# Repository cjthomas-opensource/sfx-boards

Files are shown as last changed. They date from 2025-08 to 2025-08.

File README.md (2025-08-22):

# Chris's Special-Effects Boards

## Overview

These are a series of hobby-project boards intended to produce sounds and
blinking lights. The boards are Arduino-compatible and small enough to be
packaged inside homemade toys.

Except where indicated otherwise, the files in this project are copyright (c)
2025 by Christopher Thomas and are released under the Creative Commons
Attribution-ShareAlike 4.0 International License.

**FIXME** - This really needs a user manual.

**FIXME** - Firmware code not yet folded into the repository.

## KiCad Configuration

In `Preferences`->`Configure Paths`, set `KICAD_EXT_VENDOR` to point to the
`vendor-kicad` folder.

## Folders

* `pcb-202009-9v` -- Compact board that sits on top of a 9v battery.
Needs an external clock to be programmed. Made with the "`pcb`" program
(now part of `gEDA`) rather than with KiCad.
* `pcb-202502` -- Feature-rich board with terminal block connections. Bulky
and very expensive. Made with KiCad.
* `vendor-datasheets` -- Datasheets. Under vendor copyright.
* `vendor-kicad` -- Vendor-supplied KiCad files, with additions and
modifications where appropriate. Under vendor copyright.
* `vendor-models` -- Vendor-supplied geometry models. Under vendor copyright.

## Gallery

### 2020 Board:
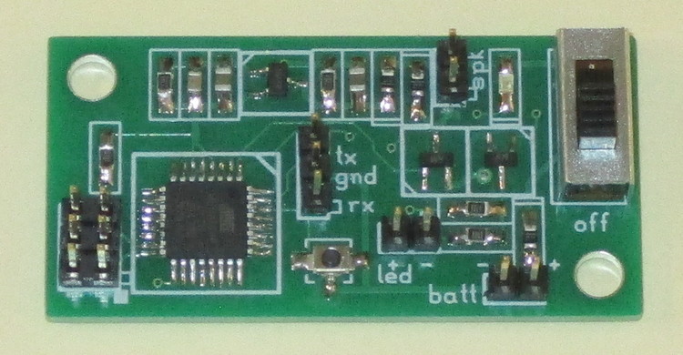
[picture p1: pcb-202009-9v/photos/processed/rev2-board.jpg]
2020 Board

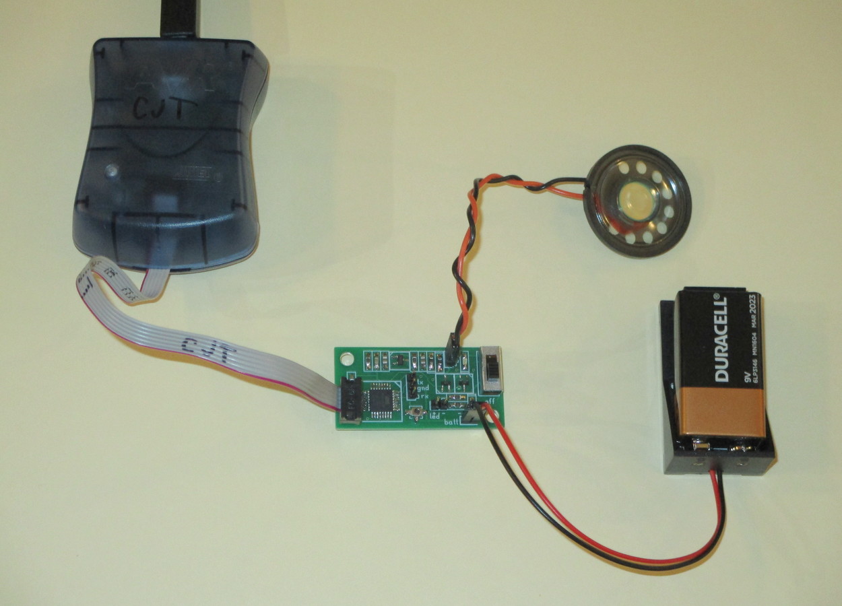
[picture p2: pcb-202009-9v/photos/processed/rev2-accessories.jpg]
2020 System


### 2025 Board:
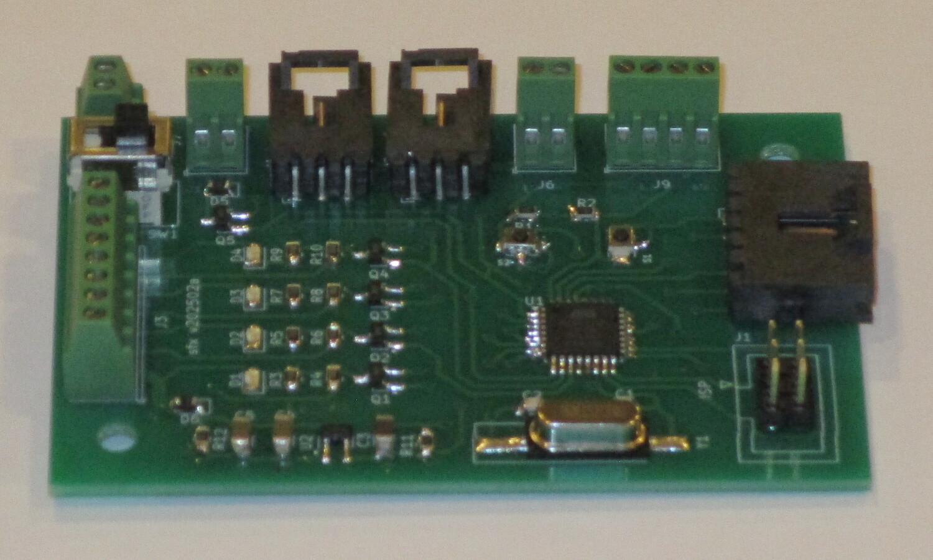
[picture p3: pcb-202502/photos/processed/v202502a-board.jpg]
2025 Board

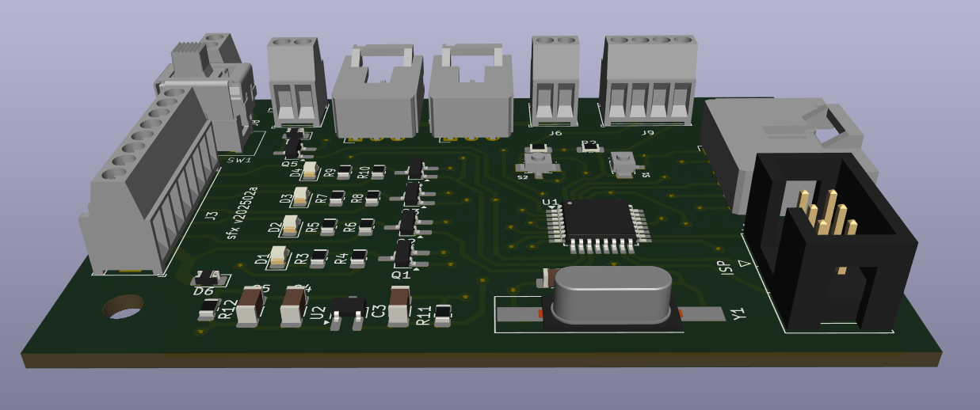
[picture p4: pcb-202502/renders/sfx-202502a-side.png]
2025 Render

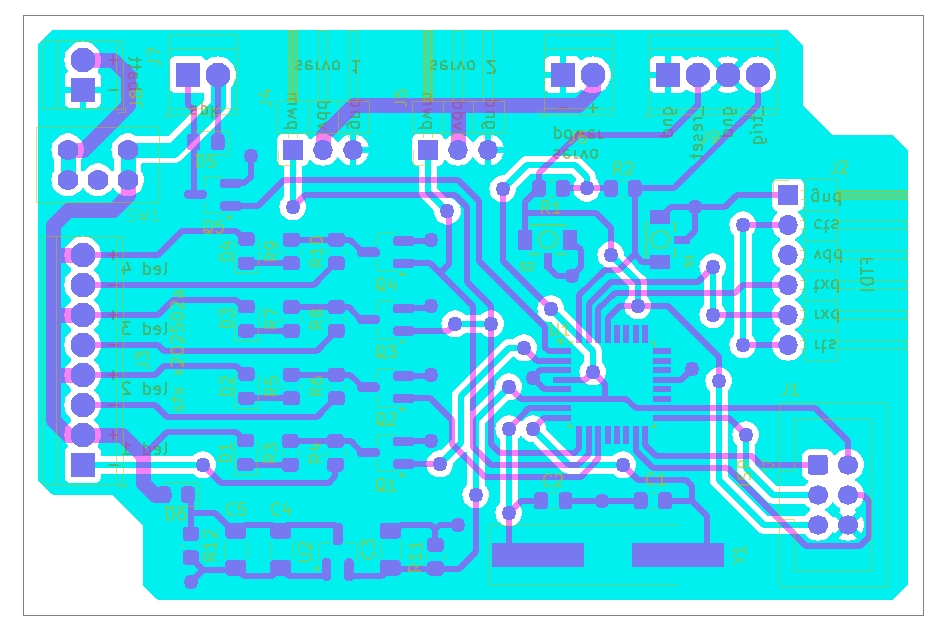
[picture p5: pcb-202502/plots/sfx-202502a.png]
2025 Layout

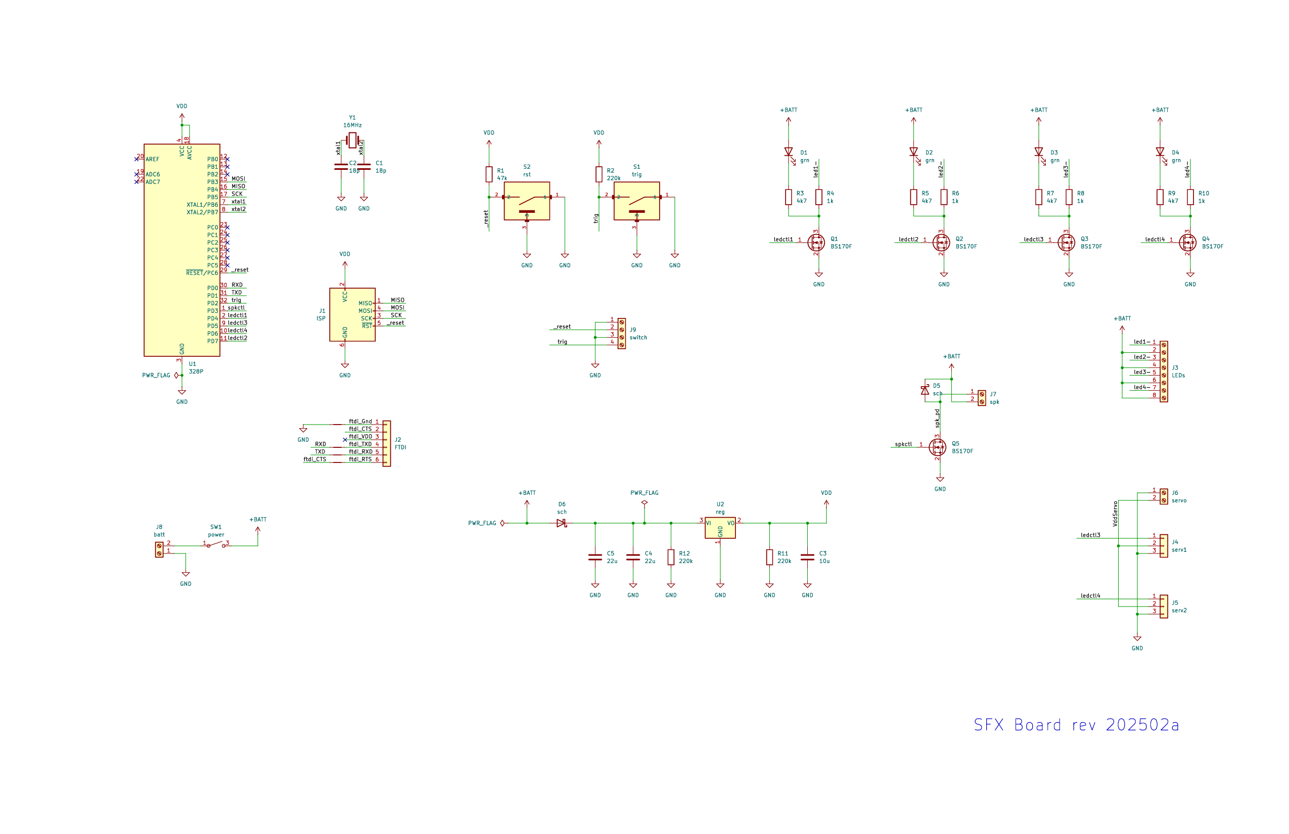
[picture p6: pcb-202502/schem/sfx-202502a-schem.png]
2025 Schematic


*This is the end of the file.*

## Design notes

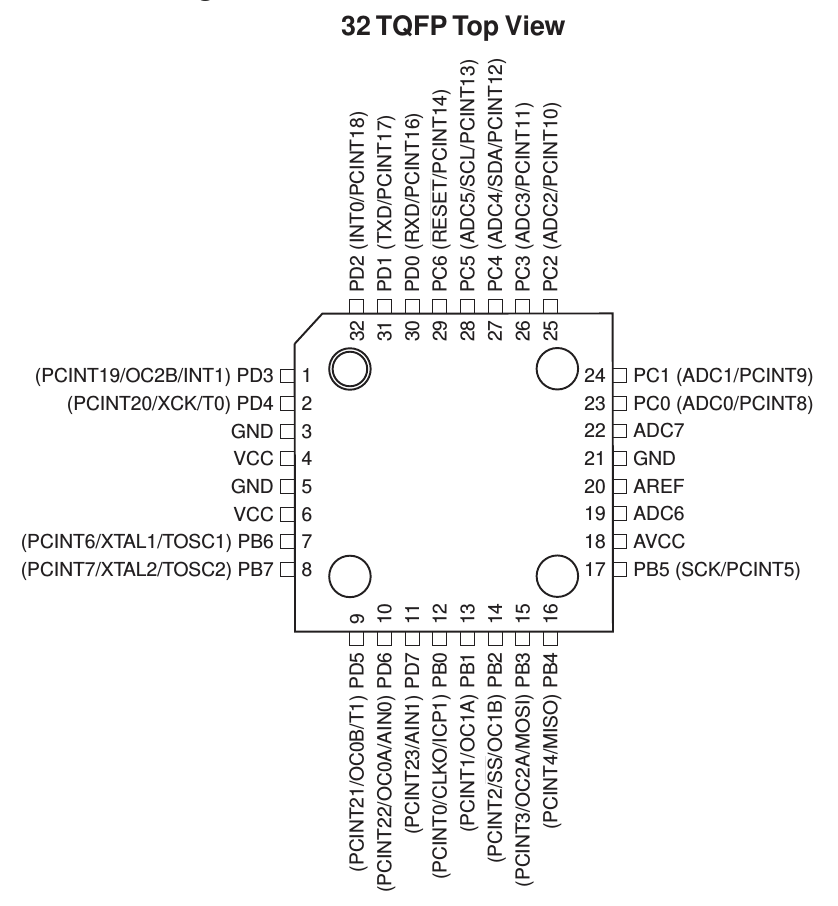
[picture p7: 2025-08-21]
vendor-datasheets/atmega328p-tqfp32-pinout.png

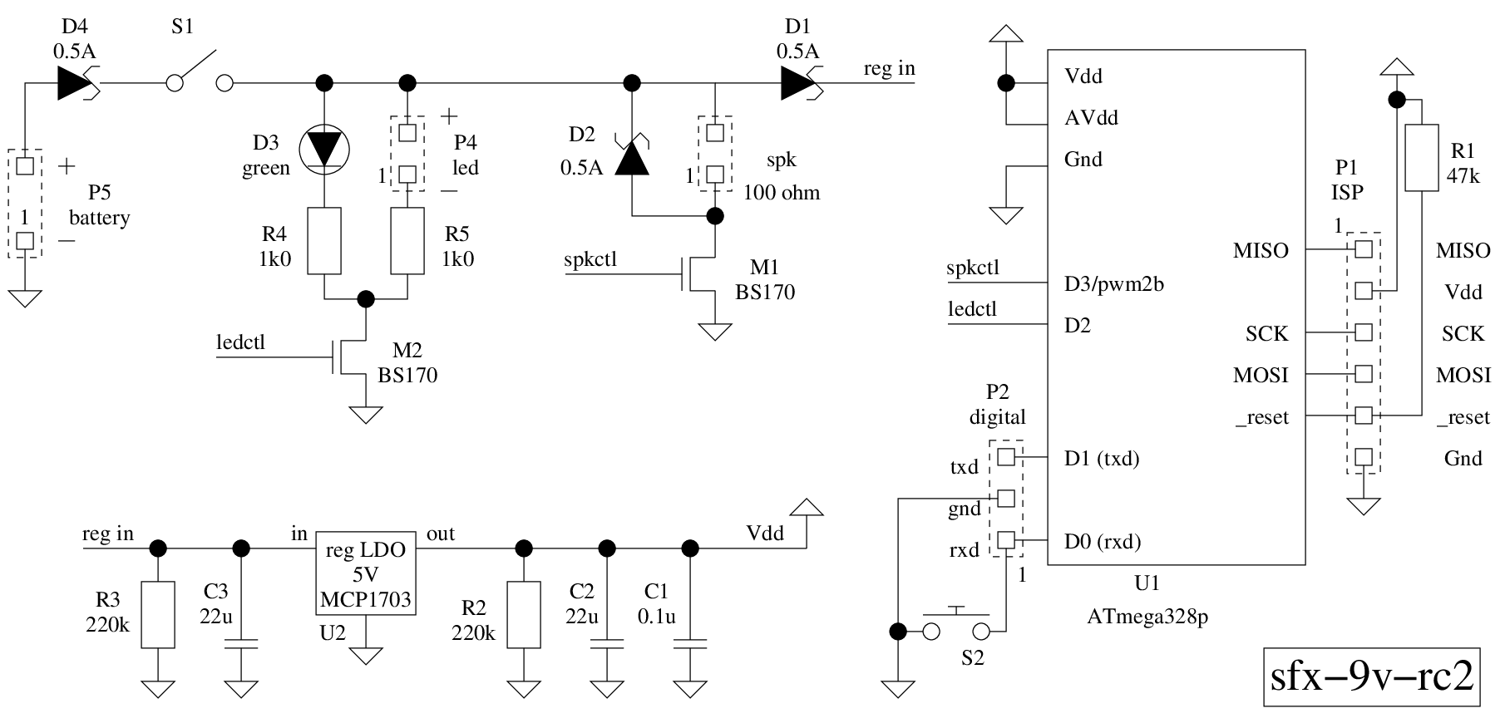
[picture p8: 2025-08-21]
pcb-202009-9v/schematic/sfx-9v-rc2-schem.png

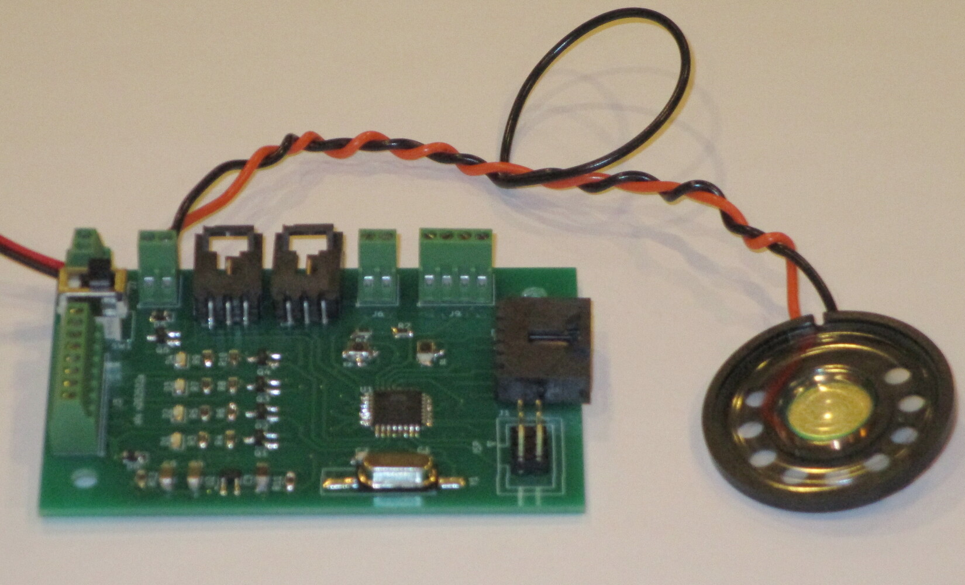
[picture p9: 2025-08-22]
pcb-202502/photos/processed/v202502a-speaker.jpg

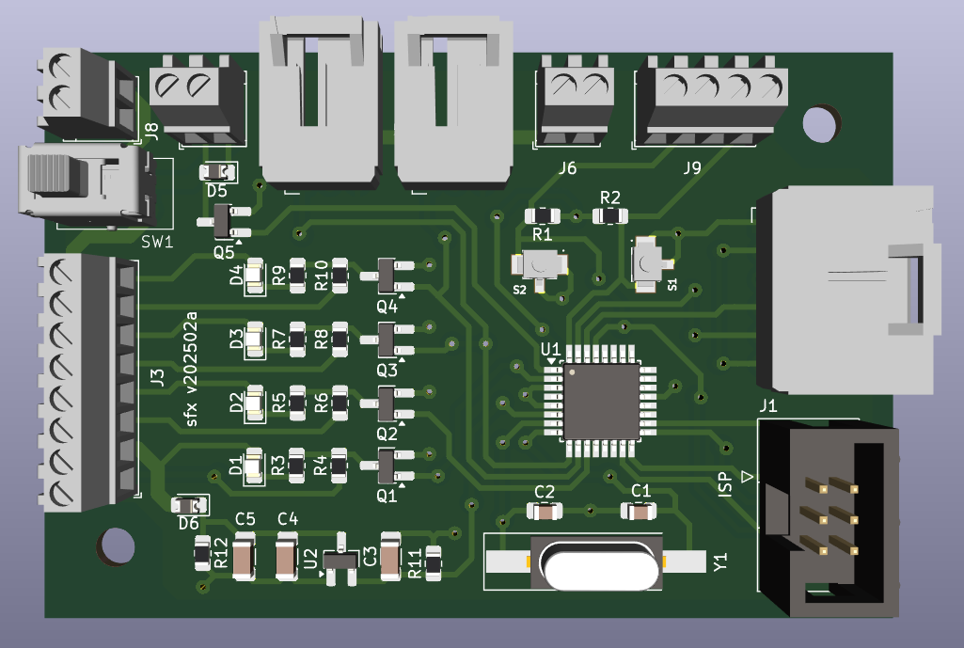
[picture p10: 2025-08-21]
pcb-202502/renders/sfx-202502a-top.png

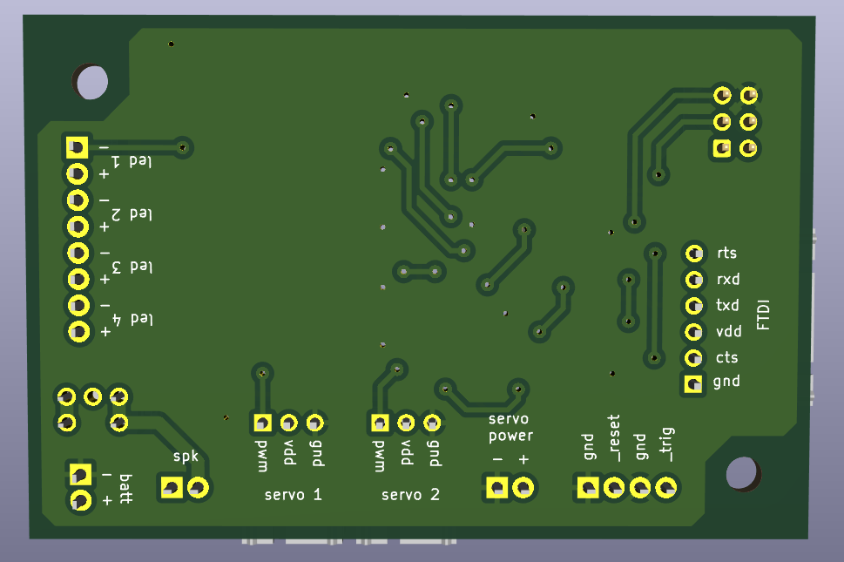
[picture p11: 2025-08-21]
pcb-202502/renders/sfx-202502a-bottom.png

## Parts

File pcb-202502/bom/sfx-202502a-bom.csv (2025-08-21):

Reference | Value | Qty | DNP | DkeyPart | MfgPart | Manufacturer
C1,C2 | 18p | 2 |  | 399-C0805C180K5GACTUCT-ND | C0805C180K5GACTU | Kemet
C3 | 10u | 1 |  | 311-1959-1-ND | CC1206KKX7R8BB106 | Yageo
C4,C5 | 22u | 2 |  | 13-CC1206KFX5R8BB226CT-ND | CC1206KFX5R8BB226 | Yageo
D1,D2,D3,D4 | grn | 4 |  | 754-1438-1-ND | APT2012ZGC | Kingbright
D5,D6 | sch | 2 |  | 478-7802-1-ND | SD0805S040S0R5 | Kyocera AVX
J1 | ISP | 1 |  | A122759-ND | 1761681-1 | TE Connectivity
J2 | FTDI | 1 |  | A28630-ND | 103906-5 | TE Connectivity
J3 | LEDs | 1 |  | A98338-ND | 282834-8 | TE Connectivity
J4 | serv1 | 1 |  | A28621-ND | 103906-2 | TE Connectivity
J5 | serv2 | 1 |  | A28621-ND | 103906-2 | TE Connectivity
J6 | servo | 1 |  | A98333-ND | 282834-2 | TE Connectivity
J7 | spk | 1 |  | A98333-ND | 282834-2 | TE Connectivity
J8 | batt | 1 |  | A98333-ND | 282834-2 | TE Connectivity
J9 | switch | 1 |  | A98335-ND | 282834-4 | TE Connectivity
Q1,Q2,Q3,Q4,Q5 | BS170F | 5 |  | BS170FCT-ND | BS170FTA | Diodes Incorporated
R1 | 47k | 1 |  | 311-47.0KCRCT-ND | RC0805FR-0747KL | Yageo
R2,R11,R12 | 220k | 3 |  | 311-220KCRCT-ND | RC0805FR-07220KL | Yageo
R3,R5,R7,R9 | 4k7 | 4 |  | 311-4.70KCRCT-ND | RC0805FR-074K7L | Yageo
R4,R6,R8,R10 | 1k | 4 |  | 311-1.00KCRCT-ND | RC0805FR-071KL | Yageo
S1 | trig | 1 |  | SW1021CT-ND | B3U-1100P | Omron Electronics
S2 | rst | 1 |  | SW1021CT-ND | B3U-1100P | Omron Electronics
SW1 | power | 1 |  | CKN1812-ND | ES02MCBE | CK Components
U1 | 328P | 1 |  | ATMEGA328P-ANRCT-ND | ATMEGA328P-ANR | Atmel
U2 | reg | 1 |  | MCP1703AT-5002E/CBCT-ND | MCP1703AT-5002E/CB | Microchip Technology
Y1 | 16MHz | 1 |  | 50-ECS-160-18-5PX-CKM-CT-ND | ECS-160-18-5PX-CKM-TR | ECS Inc

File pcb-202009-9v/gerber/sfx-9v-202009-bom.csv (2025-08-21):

Designator | Manufacturer Part Number | Qty | Link
C1 | CC0805MRX7R8BB104 | 1 | https://www.digikey.com/product-detail/en/yageo/CC0805MRX7R8BB104/311-4348-1-ND
C2, C3 | CC0805MKX5R8BB226 | 2 | https://www.digikey.com/product-detail/en/yageo/CC0805MKX5R8BB226/311-1903-1-ND
D1, D2, D4 | SD0805S040S0R5 | 2 | https://www.digikey.com/product-detail/en/avx-corporation/SD0805S040S0R5/478-7802-1-ND
D3 | APT2012ZGC | 1 | https://www.digikey.com/product-detail/en/kingbright/APT2012ZGC/754-1438-1-ND
M1, M2 | BS170FTA | 2 | https://www.digikey.com/product-detail/en/diodes-incorporated/BS170FTA/BS170FCT-ND
P1 | TSW-103-07-G-D | 1 | https://www.digikey.com/product-detail/en/samtec-inc/TSW-103-07-G-D/SAM1028-03-ND
P2 | TSW-103-07-G-S | 1 | https://www.digikey.com/product-detail/en/samtec-inc/TSW-103-07-G-S/SAM1029-03-ND
P3, P4, P5 | TSW-102-07-G-S | 3 | https://www.digikey.com/product-detail/en/samtec-inc/TSW-102-07-G-S/SAM1029-02-ND
R1 | KTR10EZPF4702 | 1 | https://www.digikey.com/product-detail/en/rohm-semiconductor/KTR10EZPF4702/RHM47-0KAHCT-ND
R2 R3 | KTR10EZPF2203 | 2 | https://www.digikey.com/product-detail/en/rohm-semiconductor/KTR10EZPF2203/RHM220KAHCT-ND
R4 R5 | ESR10EZPF1001 | 2 | https://www.digikey.com/product-detail/en/rohm-semiconductor/ESR10EZPF1001/RHM1-00KAECT-ND
S1 | SLB12814 | 1 | https://www.digikey.com/product-detail/en/apem-inc/SLB12814/679-3547-ND
S2 | B3U-1100P | 1 | https://www.digikey.com/product-detail/en/omron-electronics-inc-emc-div/B3U-1100P/SW1021CT-ND
U1 | ATMEGA328P-AU | 1 | https://www.digikey.com/product-detail/en/microchip-technology/ATMEGA328P-AU/ATMEGA328P-AU-ND
U2 | MCP1703T-5002E-CB | 1 | https://www.digikey.com/product-detail/en/microchip-technology/MCP1703T-5002E-CB/MCP1703T-5002E-CBCT-ND

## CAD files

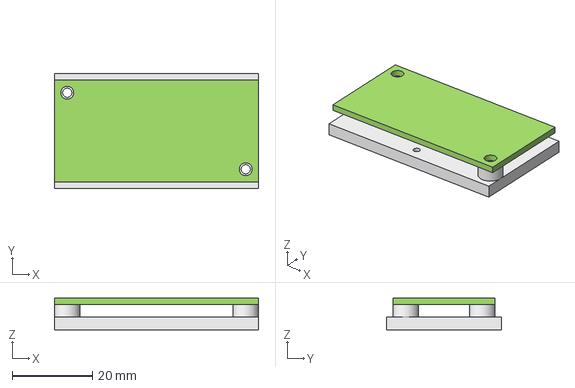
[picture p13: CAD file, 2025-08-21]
pcb-202009-9v/mech/adapter-sfx-9v.fcstd
50.8 x 28.6 x 7.94 mm
adapter with holes
pcb

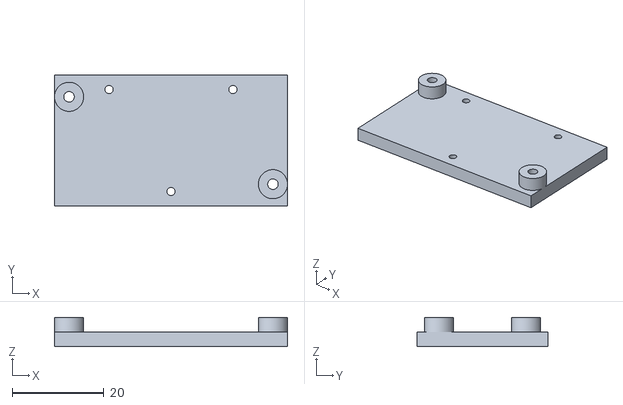
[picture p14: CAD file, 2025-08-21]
pcb-202009-9v/mech/meshes/adapter-sfx-9v.stl
50.8 x 28.6 x 6.35

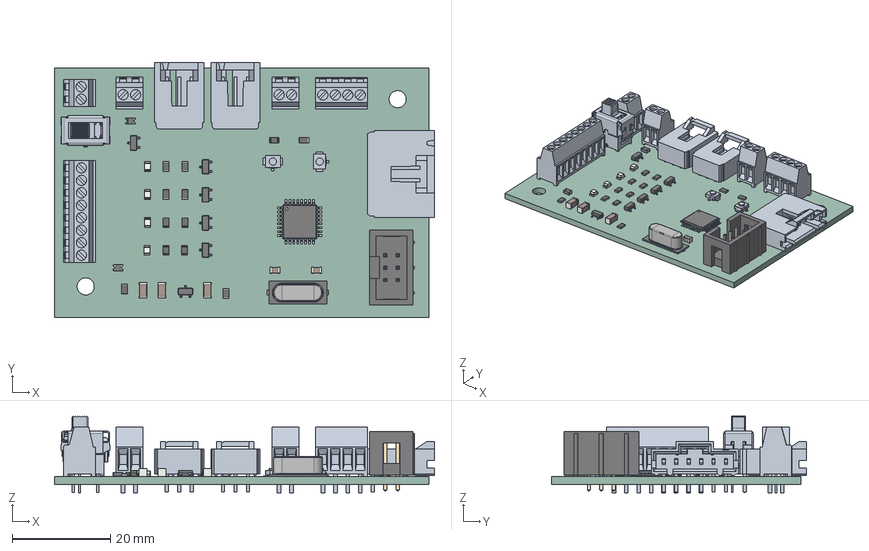
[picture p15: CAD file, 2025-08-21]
pcb-202502/model/sfx-202502a.step
77.3 x 51.9 x 15.7 mm
R_0805_2012Metric x 12
C_0805_2012Metric x 2
LED_0805_2012Metric x 4
SOT_23 x 6
C_1206_3216Metric x 3
TQFP_32_7x7mm_P08mm
B3U_1100P[] x 2
C-282834-8
D_0805 x 2
Crystal_SMD_HC49-SD
ES02MCBE
IDC_Header_2x03_P254mm_Vertical
C-282834-4
sfx-202502_PCB

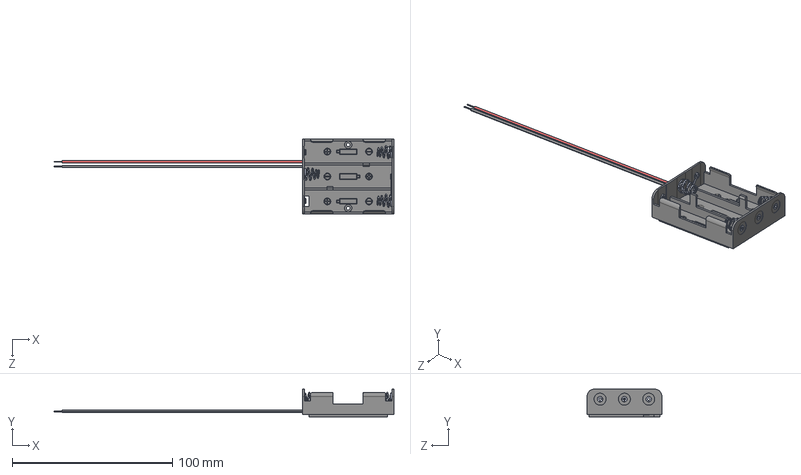
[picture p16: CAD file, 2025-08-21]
vendor-kicad/mpd-batt-models/BH3AA-W.step
212.1 x 17.4 x 46.6 mm

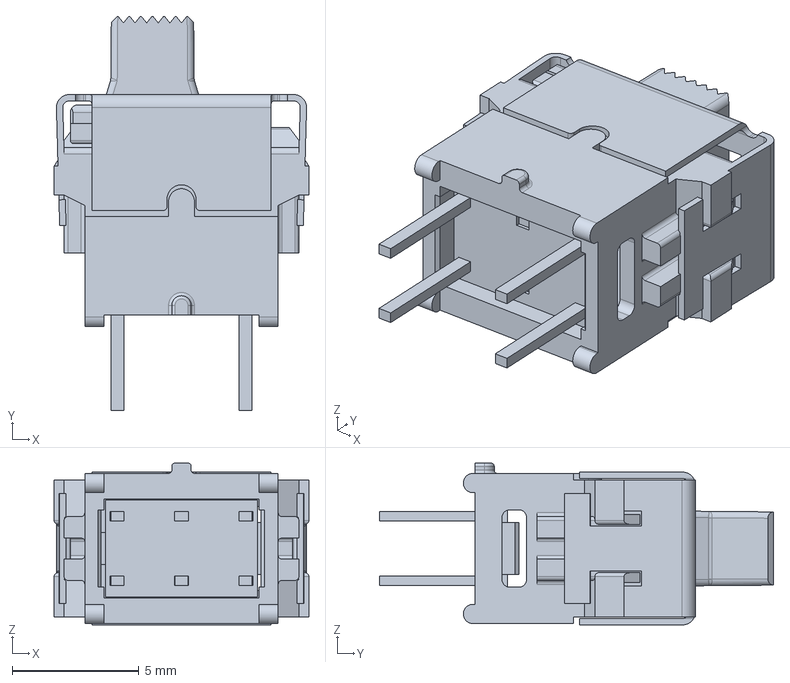
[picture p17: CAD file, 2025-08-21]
vendor-kicad/switch-ck-spst-vert-ES02MCBE/ES02MCBE.step
10.0 x 15.5 x 6.38 mm
ES02MCBE_PART1
ES02MCBE_PART2
ES02MCBE_PART3

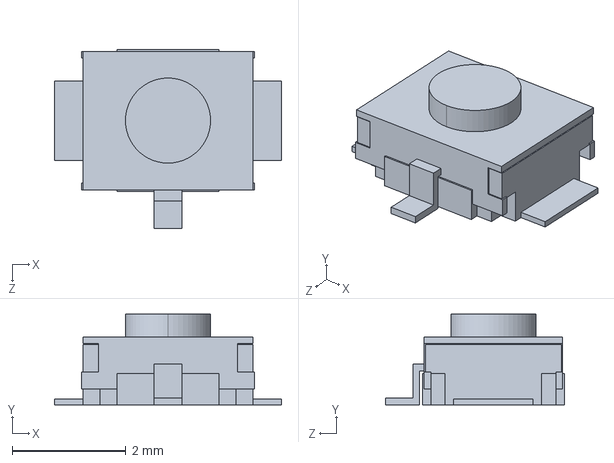
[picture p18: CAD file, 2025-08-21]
vendor-kicad/switch-smt-pb-Omron-B3U_1100P/B3U-1100P.step
4.00 x 1.60 x 3.15 mm

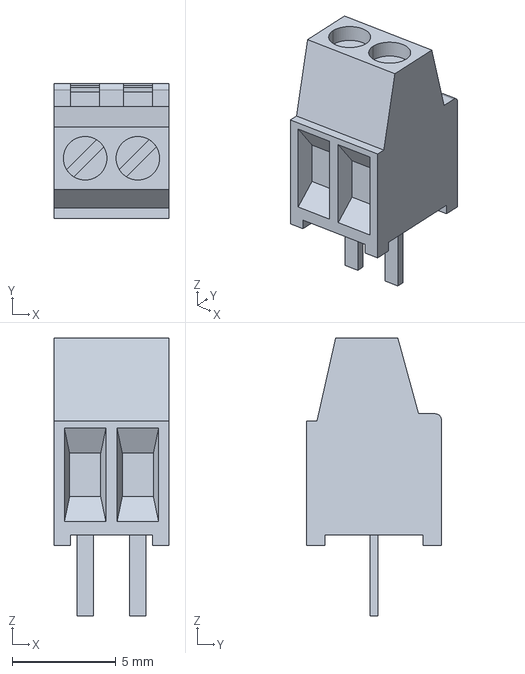
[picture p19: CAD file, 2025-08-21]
vendor-kicad/te-conn-models/term-2pos-100mil-282834-2.stp
5.54 x 6.50 x 13.4 mm

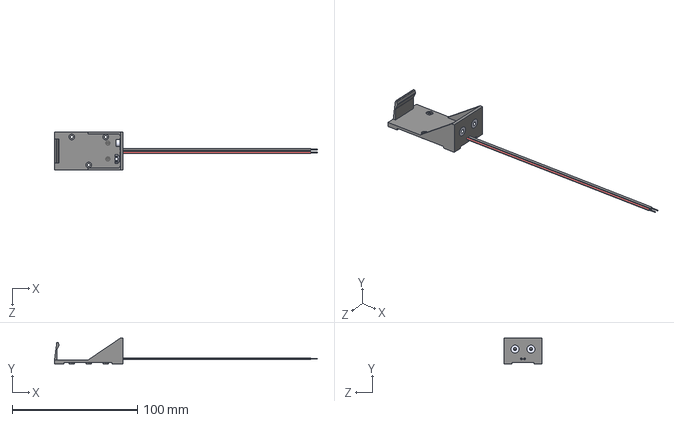
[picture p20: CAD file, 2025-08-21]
vendor-models/BH9VW.step
209.6 x 20.6 x 30.0 mm

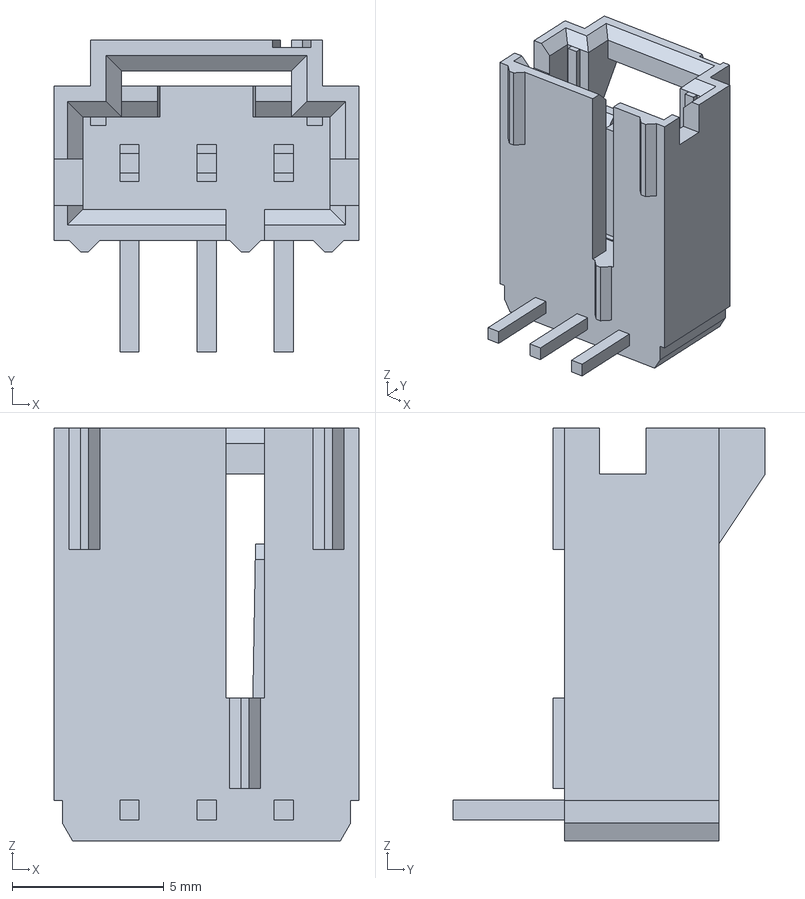
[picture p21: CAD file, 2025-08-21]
vendor-kicad/te-conn-models/conn-01x03-m-shr-103906-2.stp
10.0 x 10.3 x 13.6 mm

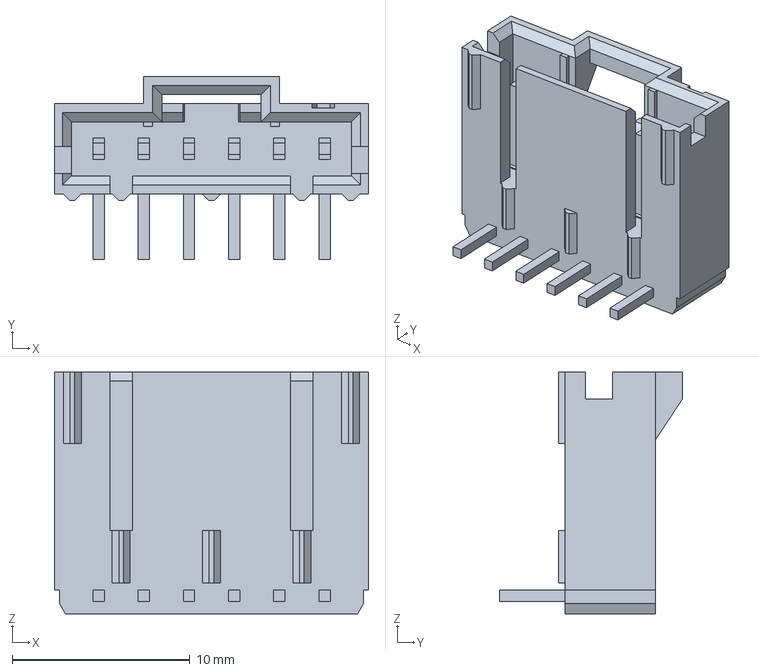
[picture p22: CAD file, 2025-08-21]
vendor-kicad/te-conn-models/conn-01x06-m-shr-103906-5.stp
17.7 x 10.3 x 13.6 mm

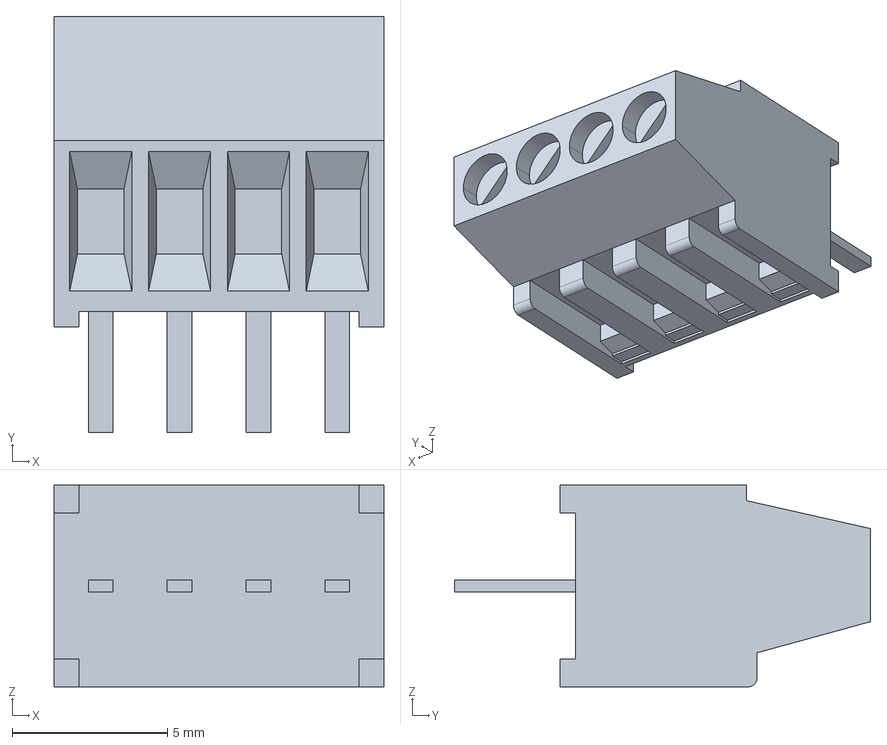
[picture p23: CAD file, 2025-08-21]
vendor-kicad/te-conn-models/term-4pos-100mil-282834-4.stp
10.6 x 13.4 x 6.50 mm

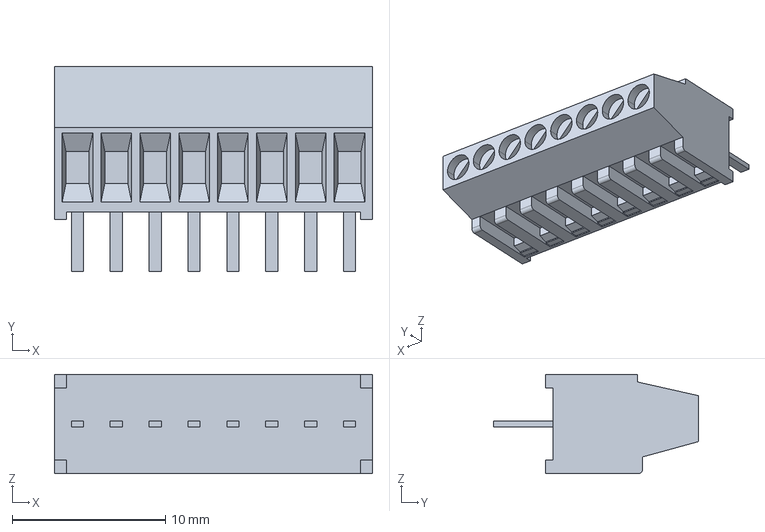
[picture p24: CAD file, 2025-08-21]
vendor-kicad/te-conn-models/term-8pos-100mil-282834-8.stp
20.8 x 13.4 x 6.50 mm

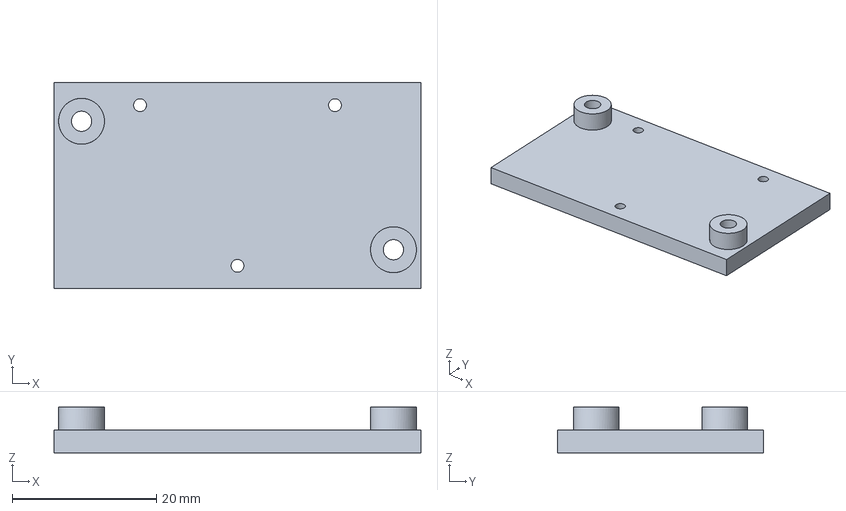
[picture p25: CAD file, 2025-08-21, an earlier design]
pcb-202009-9v/mech/iges/adapter-sfx-9v-rc2-deprecated.iges
50.8 x 28.6 x 6.35 mm

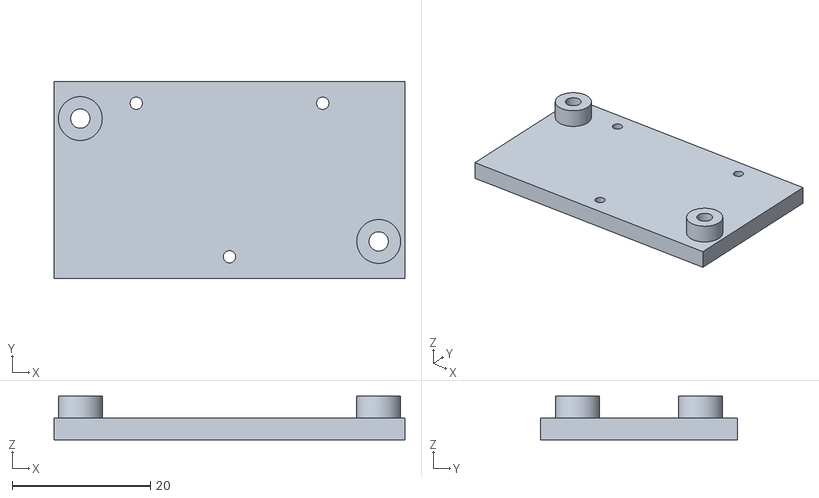
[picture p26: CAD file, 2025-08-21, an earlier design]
pcb-202009-9v/mech/meshes/adapter-sfx-9v-rc2-deprecated.stl
50.8 x 28.6 x 6.35

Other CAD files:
pcb-202009-9v/mech/iges/adapter-sfx-9v.iges

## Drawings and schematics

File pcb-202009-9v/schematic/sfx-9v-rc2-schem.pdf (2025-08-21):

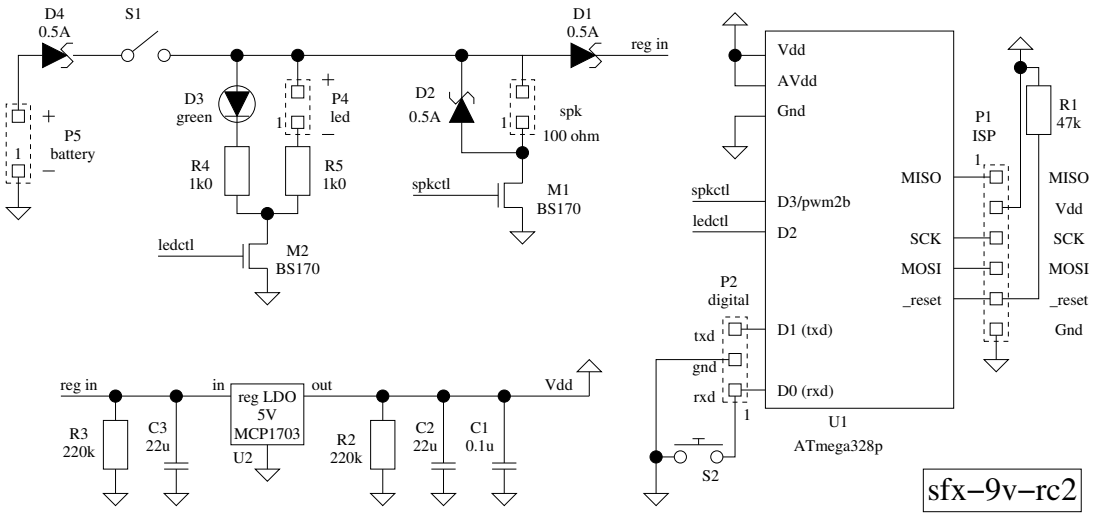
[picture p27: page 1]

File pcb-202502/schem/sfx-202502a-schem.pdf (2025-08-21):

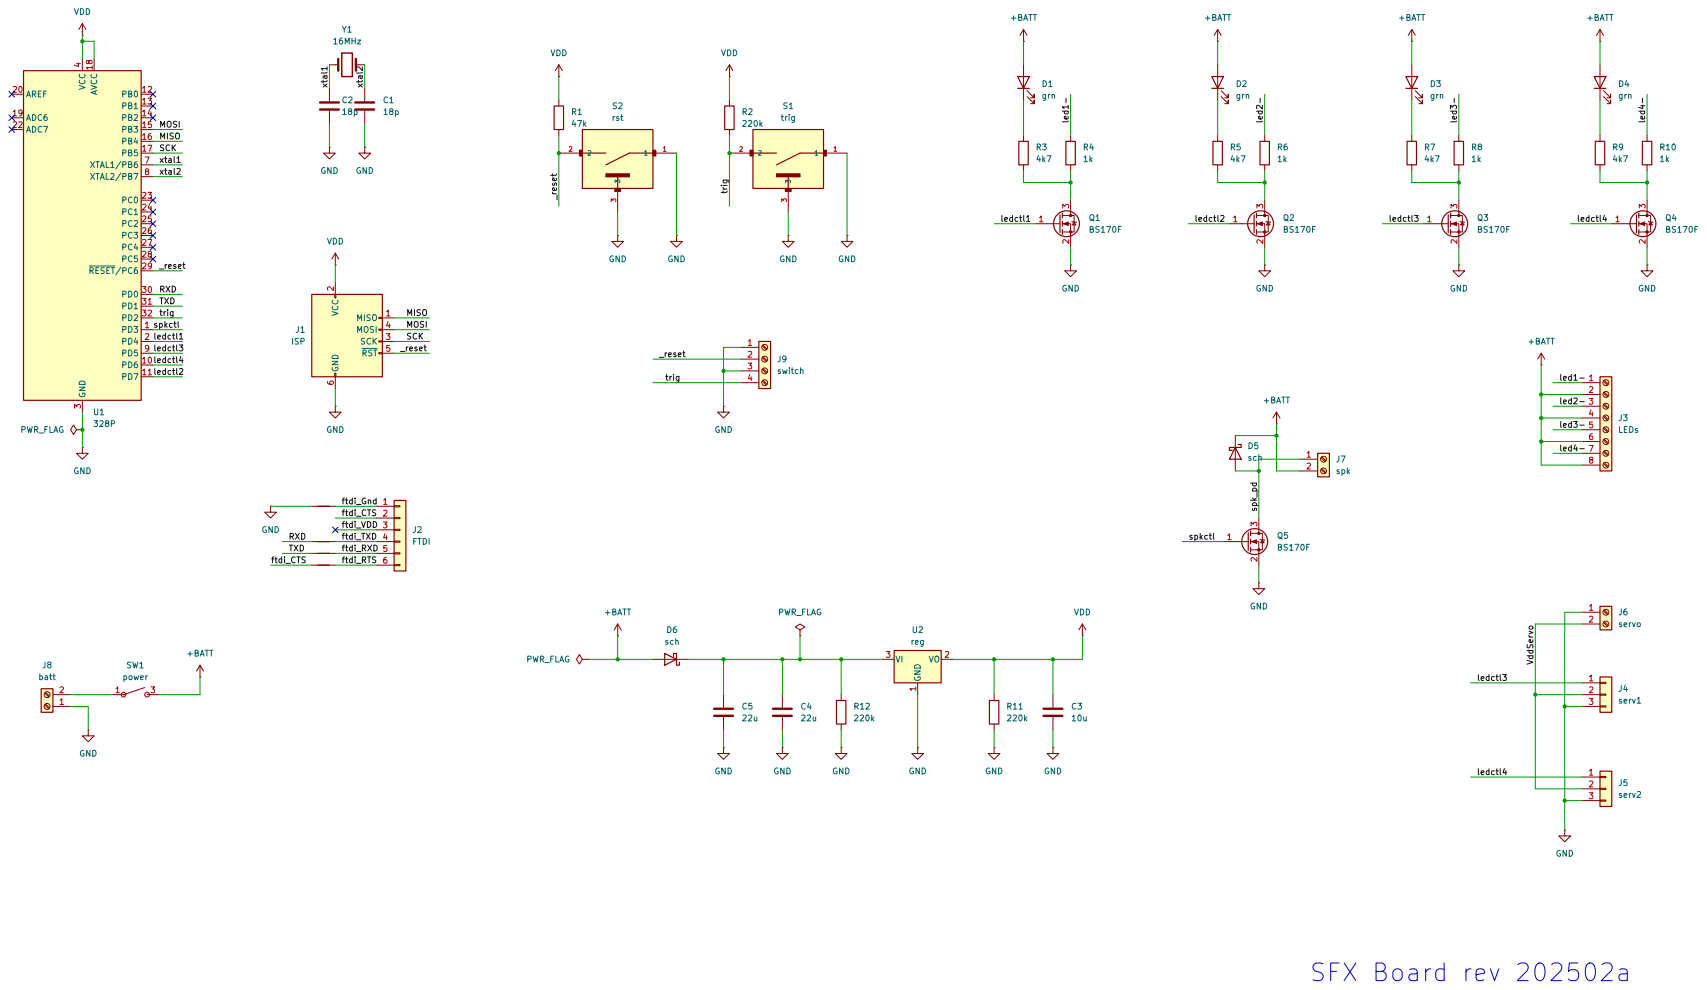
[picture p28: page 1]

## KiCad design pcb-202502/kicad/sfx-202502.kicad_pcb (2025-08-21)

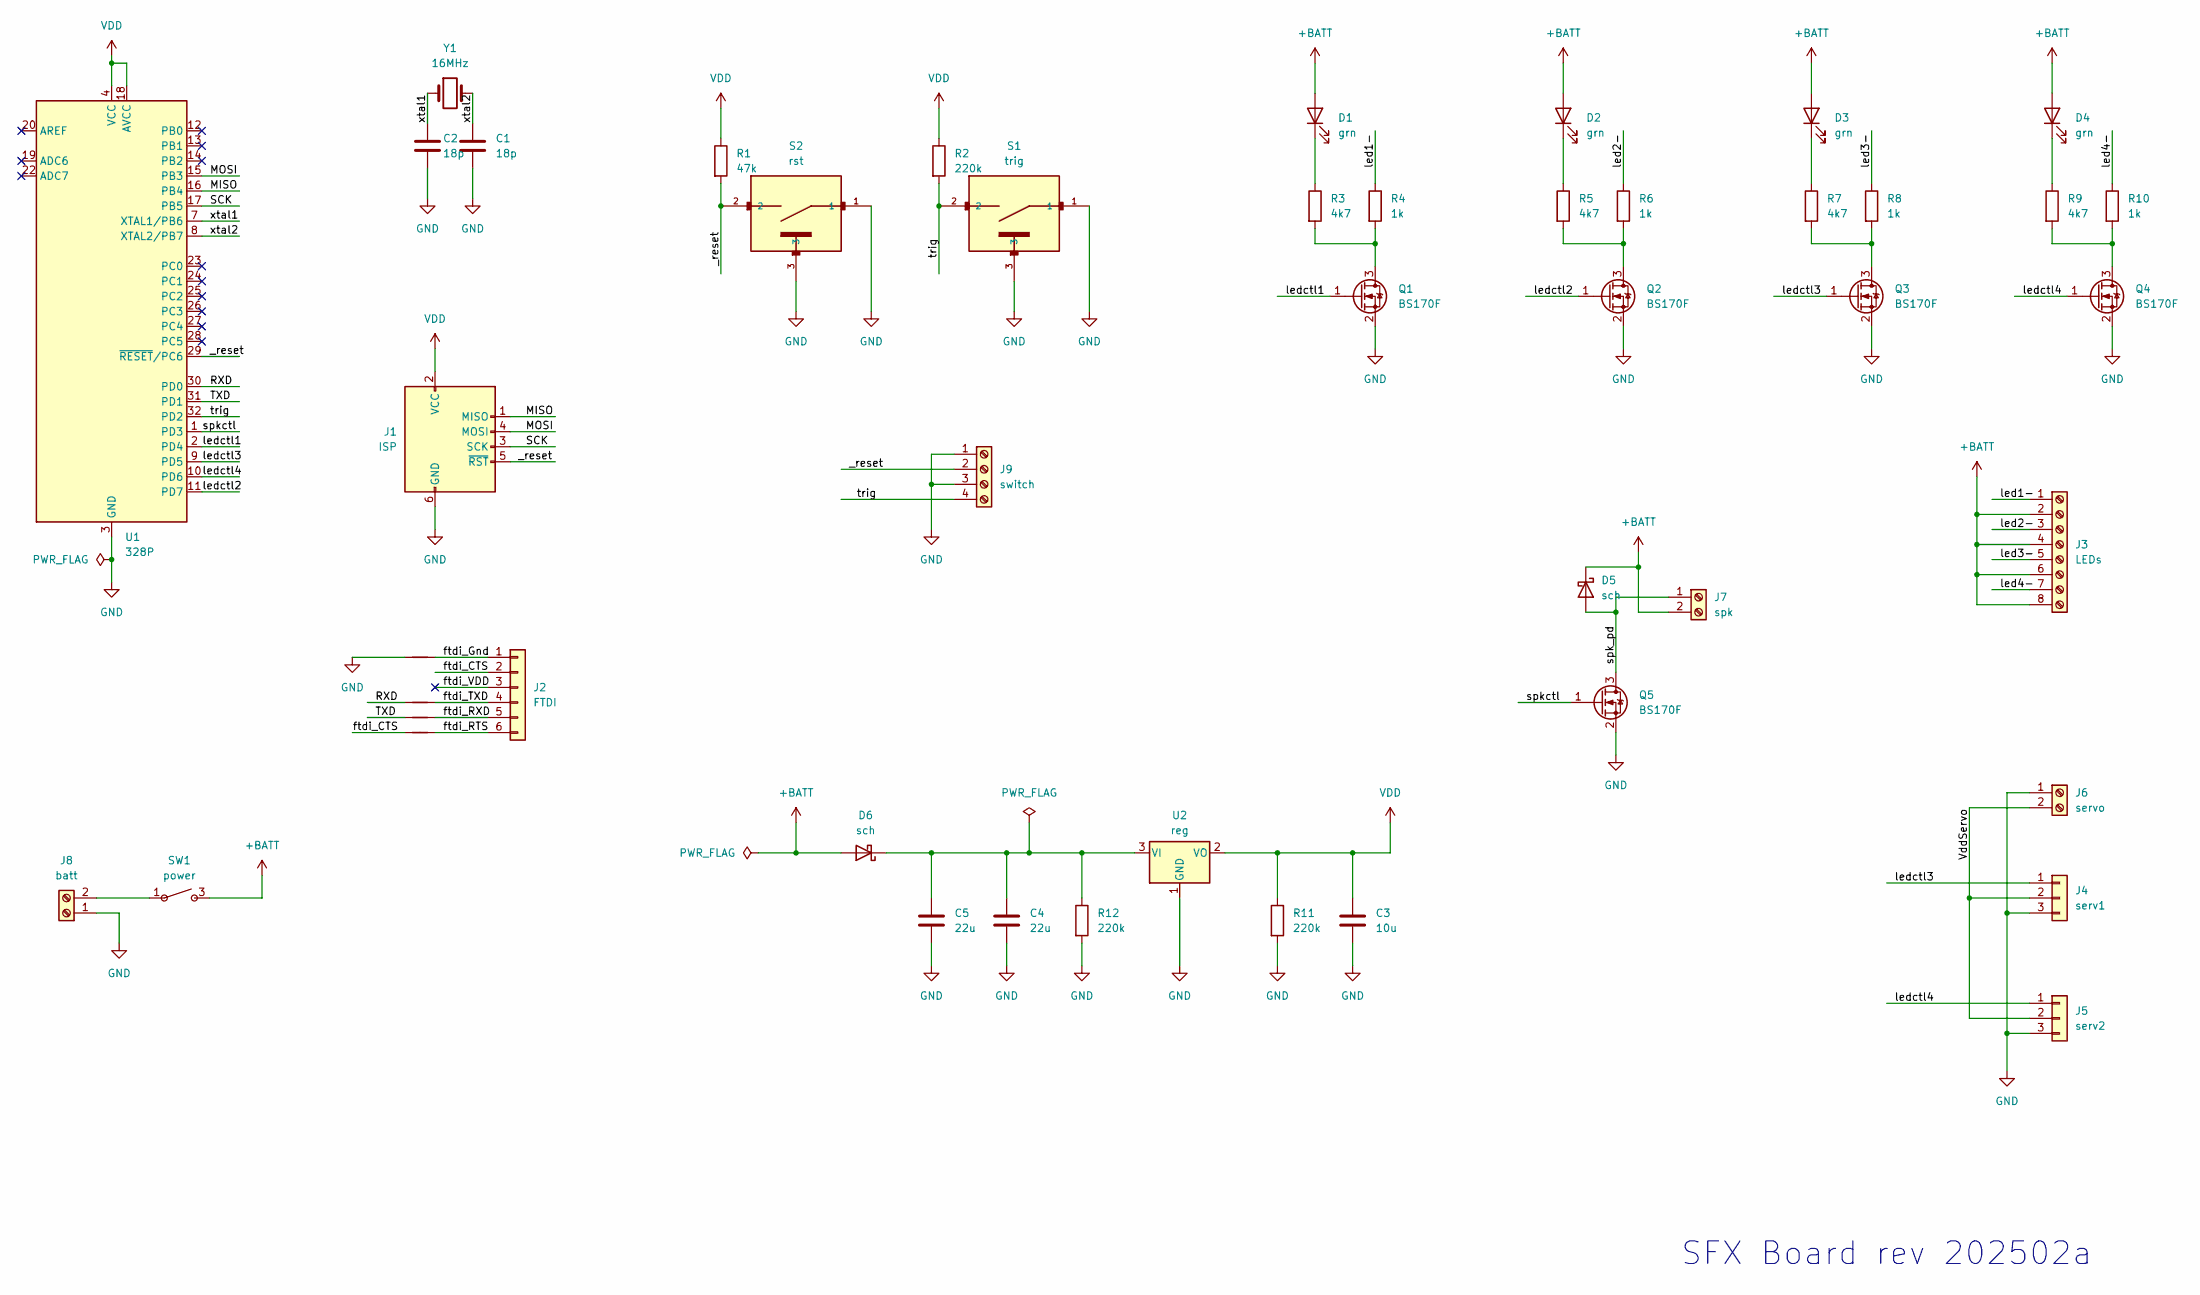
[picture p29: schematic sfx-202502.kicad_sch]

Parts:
C1, C2: 18p; C_0805_2012Metric_Pad1.18x1.45mm_HandSolder; MfgPart C0805C180K5GACTU
C3: 10u; C_1206_3216Metric_Pad1.33x1.80mm_HandSolder; MfgPart CC1206KKX7R8BB106
C4, C5: 22u; C_1206_3216Metric_Pad1.33x1.80mm_HandSolder; MfgPart CC1206KFX5R8BB226
D1, D2, D3, D4: grn; LED_0805_2012Metric_Pad1.15x1.40mm_HandSolder; MfgPart APT2012ZGC
D5, D6: sch; D_0805_2012Metric_Pad1.15x1.40mm_HandSolder; MfgPart SD0805S040S0R5
J1: ISP; IDC-Header_2x03_P2.54mm_Vertical; MfgPart 1761681-1
J2: FTDI; PinHeader_1x06_P2.54mm_Horizontal; MfgPart 103906-5
J3: LEDs; TerminalBlock_TE_282834-8_1x08_P2.54mm_Horizontal; MfgPart 282834-8
J4: serv1; PinHeader_1x03_P2.54mm_Horizontal; MfgPart 103906-2
J5: serv2; PinHeader_1x03_P2.54mm_Horizontal; MfgPart 103906-2
J6: servo; TerminalBlock_TE_282834-2_1x02_P2.54mm_Horizontal; MfgPart 282834-2
J7: spk; TerminalBlock_TE_282834-2_1x02_P2.54mm_Horizontal; MfgPart 282834-2
J8: batt; TerminalBlock_TE_282834-2_1x02_P2.54mm_Horizontal; MfgPart 282834-2
J9: switch; TerminalBlock_TE_282834-4_1x04_P2.54mm_Horizontal; MfgPart 282834-4
NT1, NT2, NT3, NT4: NetTie_2; NetTie-2_SMD_Pad0.5mm
Q1, Q2, Q3, Q4, Q5: BS170F; SOT-23_Handsoldering; MfgPart BS170FTA
R1: 47k; R_0805_2012Metric_Pad1.20x1.40mm_HandSolder; MfgPart RC0805FR-0747KL
R2, R11, R12: 220k; R_0805_2012Metric_Pad1.20x1.40mm_HandSolder; MfgPart RC0805FR-07220KL
R3, R5, R7, R9: 4k7; R_0805_2012Metric_Pad1.20x1.40mm_HandSolder; MfgPart RC0805FR-074K7L
R4, R6, R8, R10: 1k; R_0805_2012Metric_Pad1.20x1.40mm_HandSolder; MfgPart RC0805FR-071KL
S1: trig; SW_B3U-1100P; MfgPart B3U-1100P
S2: rst; SW_B3U-1100P; MfgPart B3U-1100P
SW1: power; Switch_Slide_SPST_CK_ES02MCBE; MfgPart ES02MCBE
U1: 328P; TQFP-32_7x7mm_P0.8mm; MfgPart ATMEGA328P-ANR
U2: reg; SOT-23_Handsoldering; MfgPart MCP1703AT-5002E/CB
Y1: 16MHz; Crystal_SMD_HC49-SD_HandSoldering; MfgPart ECS-160-18-5PX-CKM-TR

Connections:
+BATT: D1.2 (A), D2.2 (A), D3.2 (A), D4.2 (A), D5.1 (K), D6.2 (A), J3.2, J3.4, J3.6, J3.8, J7.2, SW1.3 (B), SW1.6 (nc)
/MISO: J1.1 (MISO), U1.16 (PB4)
/MOSI: J1.4 (MOSI), U1.15 (PB3)
/RXD: NT2.1, U1.30 (PD0)
/SCK: J1.3 (SCK), U1.17 (PB5)
/TXD: NT3.1, U1.31 (PD1)
/VddServo: J4.2, J5.2, J6.2
/_reset: J1.5 (~RST), J9.2, R1.2, S2.2, U1.29 (~RESET/PC6)
/ftdi_CTS: J2.2, NT4.1
/ftdi_Gnd: J2.1, NT1.2
/ftdi_RTS: J2.6, NT4.2
/ftdi_RXD: J2.5, NT3.2
/ftdi_TXD: J2.4, NT2.2
/ftdi_VDD: J2.3
/led1-: J3.1, R4.1
/led2-: J3.3, R6.1
/led3-: J3.5, R8.1
/led4-: J3.7, R10.1
/ledctl1: Q1.1 (G), U1.2 (PD4)
/ledctl2: Q2.1 (G), U1.11 (PD7)
/ledctl3: J4.1, Q3.1 (G), U1.9 (PD5)
/ledctl4: J5.1, Q4.1 (G), U1.10 (PD6)
/spk_pd: D5.2 (A), J7.1, Q5.3 (D)
/spkctl: Q5.1 (G), U1.1 (PD3)
/trig: J9.4, R2.2, S1.2, U1.32 (PD2)
/xtal1: C2.1, U1.7 (XTAL1/PB6), Y1.1
/xtal2: C1.1, U1.8 (XTAL2/PB7), Y1.2
GND: C1.2, C2.2, C3.2, C4.2, C5.2, J1.6 (GND), J4.3, J5.3, J6.1, J8.1, J9.1, J9.3, NT1.1, Q1.2 (S), Q2.2 (S), Q3.2 (S), Q4.2 (S), Q5.2 (S), R11.2, R12.2, S1.1, S1.3, S2.1, S2.3, U1.3 (GND), U1.5 (GND), U1.21 (GND), U2.1 (GND)
unnamed: D1.1 (K), R3.1
unnamed: D2.1 (K), R5.1
unnamed: D3.1 (K), R7.1
unnamed: D4.1 (K), R9.1
unnamed: C4.1, C5.1, D6.1 (K), R12.1, U2.3 (VI)
unnamed: Q1.3 (D), R3.2, R4.2
unnamed: Q2.3 (D), R5.2, R6.2
unnamed: Q3.3 (D), R7.2, R8.2
unnamed: Q4.3 (D), R9.2, R10.2
VDD: C3.1, J1.2 (VCC), R1.1, R2.1, R11.1, U1.4 (VCC), U1.6 (VCC), U1.18 (AVCC), U2.2 (VO)

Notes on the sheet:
SFX Board rev 202502a

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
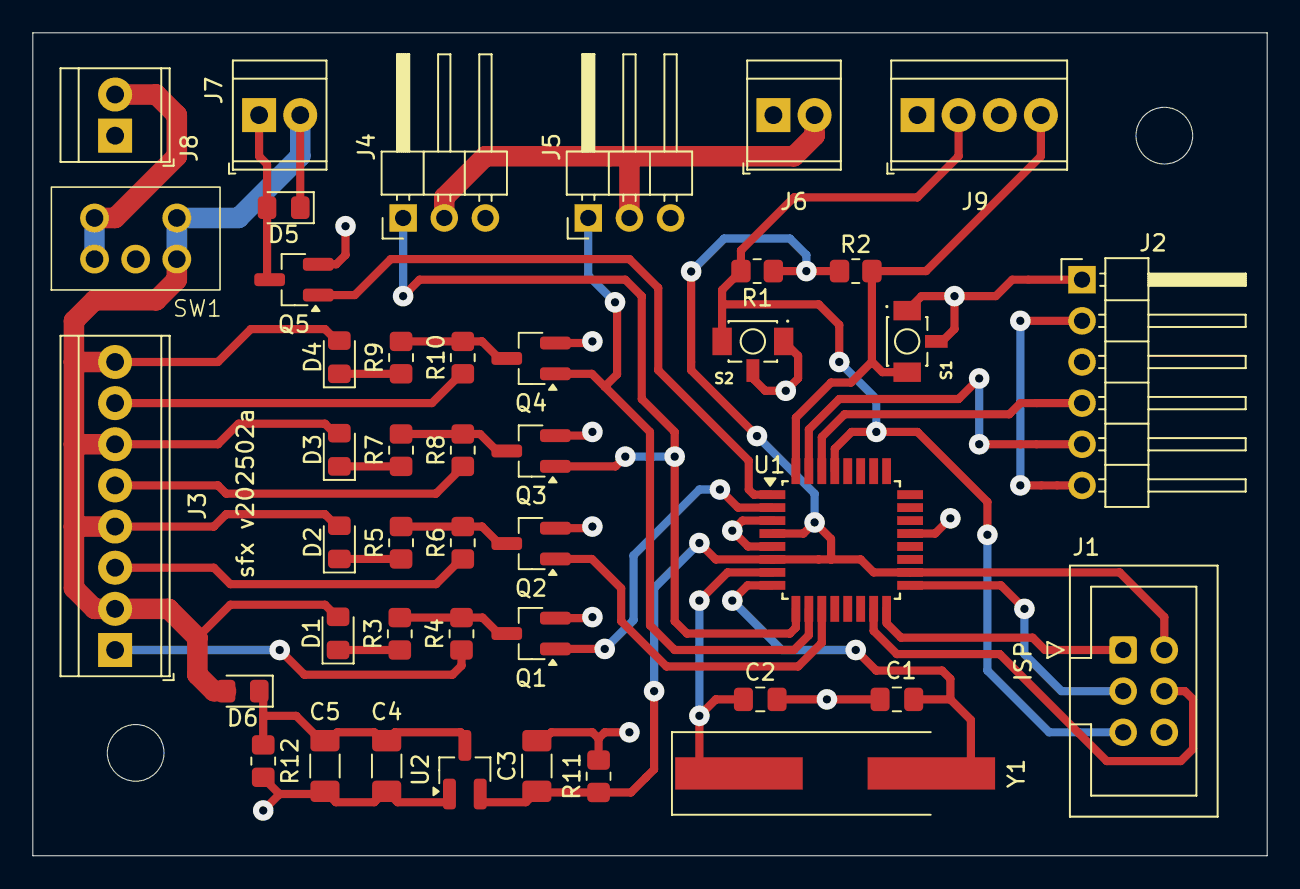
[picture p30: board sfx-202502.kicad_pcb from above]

Board: 2 copper layers, 76.2 x 50.8 mm, 47 parts (0 on the bottom side), 38 nets.

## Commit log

2025-08-21 Initial repository. Missing firmware and sound samples.
    [B3U-1100P.step, BH3AA-W.step, BH9VW.step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]
2025-08-22 Fixed capitalization in KiCad.

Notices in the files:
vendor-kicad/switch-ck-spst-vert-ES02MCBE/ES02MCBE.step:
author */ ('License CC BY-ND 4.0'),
